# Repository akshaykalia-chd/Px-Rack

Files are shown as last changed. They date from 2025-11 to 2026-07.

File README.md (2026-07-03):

## What is a PX-Rack

Personal Experience Rack, or PX-Rack, is a modular DIY computer rack-style enclosure built for creators who value scalability, customization, and hands-on engineering. Designed to integrate multiple [Mini-ITX](https://en.wikipedia.org/wiki/Mini-ITX) motherboards into a single compact unit, PX-Rack is ideal for homelabs, clustered compute nodes, or multi-OS test environments.

The first use case is [Broadcom VMware Cloud Foundation](https://www.vmware.com/products/cloud-infrastructure/vmware-cloud-foundation). 

## 🛠️ Skills Required to Build a PX-Rack

Building a PX-Rack is not a beginner project. You will need:

1. **Miter saw** — for cutting extrusions and structural components to precise lengths
2. **Soldering** — primarily a safety net for human error during wiring
3. **Specialty tools** — screwdrivers and Allen keys in M2, M3, and M4 sizes, plus Torx drivers T2, T3, and T4
4. **ATX power supply disassembly** — you will need to open and modify a standard ATX PSU

> If any of these sound daunting, that is perfectly reasonable. Reach out using the details in the [Contact details](#-contact-details) section to order a pre-built PX-Rack — or engage directly with the designer if you are mad enough to attempt this yourself.

### 2-Node PX-Rack Enclosure: ### 
#### Render:
2-Node Render

#### Actual: 

Not built, hence no images are available. However, it will be identical to the bottom half of a 4-node enclosure.

### 4-Node PX-Rack Enclosure: ### 
#### Render:
4-Node Render

#### Actual:
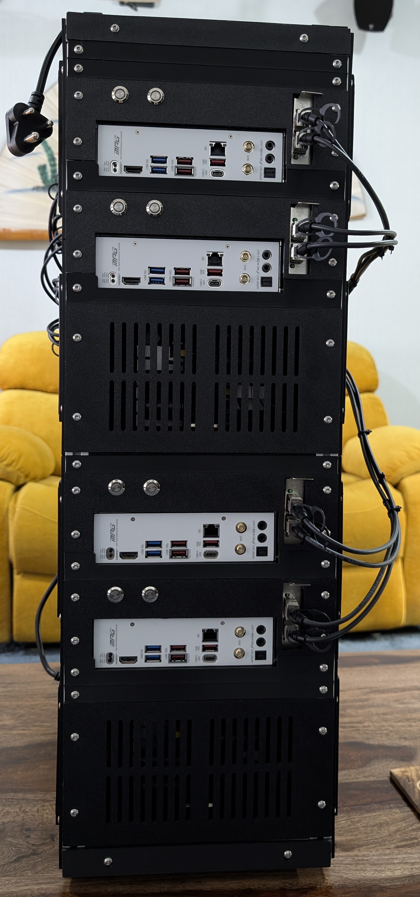
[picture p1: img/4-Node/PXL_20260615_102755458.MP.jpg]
4-Node actual 1

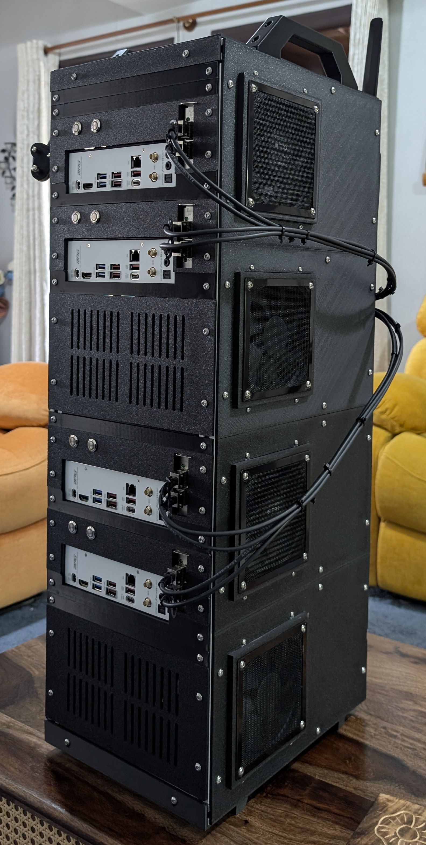
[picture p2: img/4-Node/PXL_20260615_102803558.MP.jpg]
4-Node actual 2

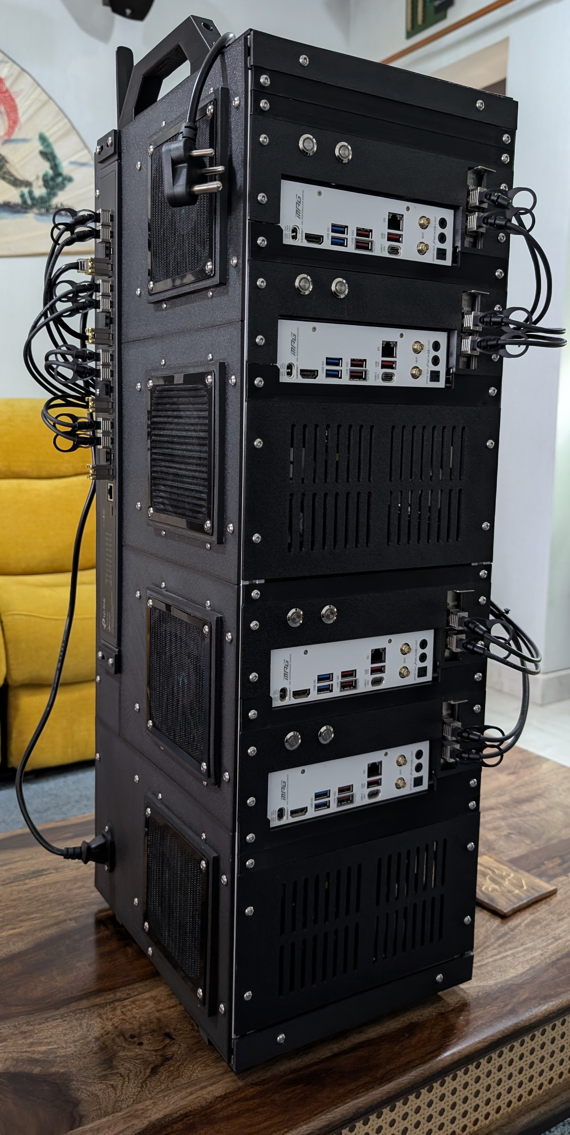
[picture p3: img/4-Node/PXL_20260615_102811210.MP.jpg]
4-Node actual 3

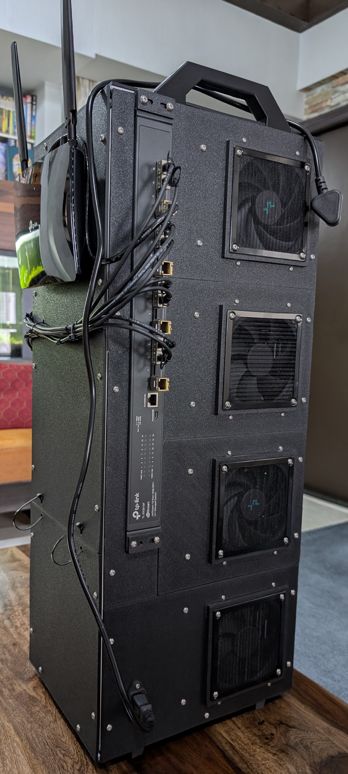
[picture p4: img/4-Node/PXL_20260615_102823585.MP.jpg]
4-Node actual 4

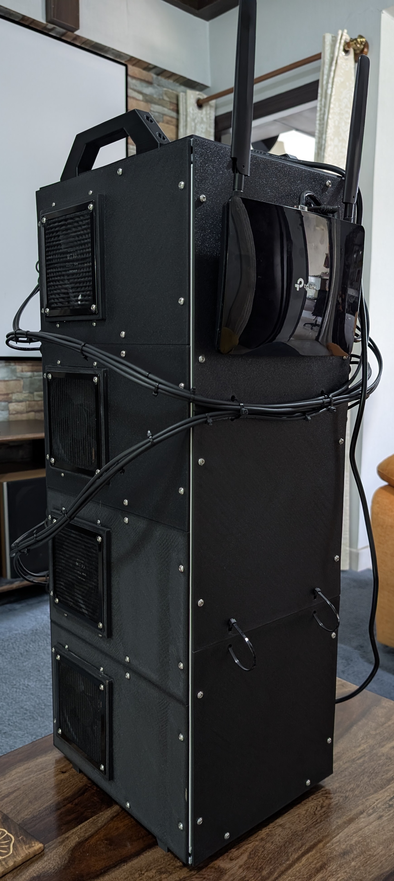
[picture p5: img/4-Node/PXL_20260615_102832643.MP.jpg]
4-Node actual 5


### PX-Rack vs Full Tower
On the left is PX-Rack, and on the right is the Cooler Master Full Tower Case.

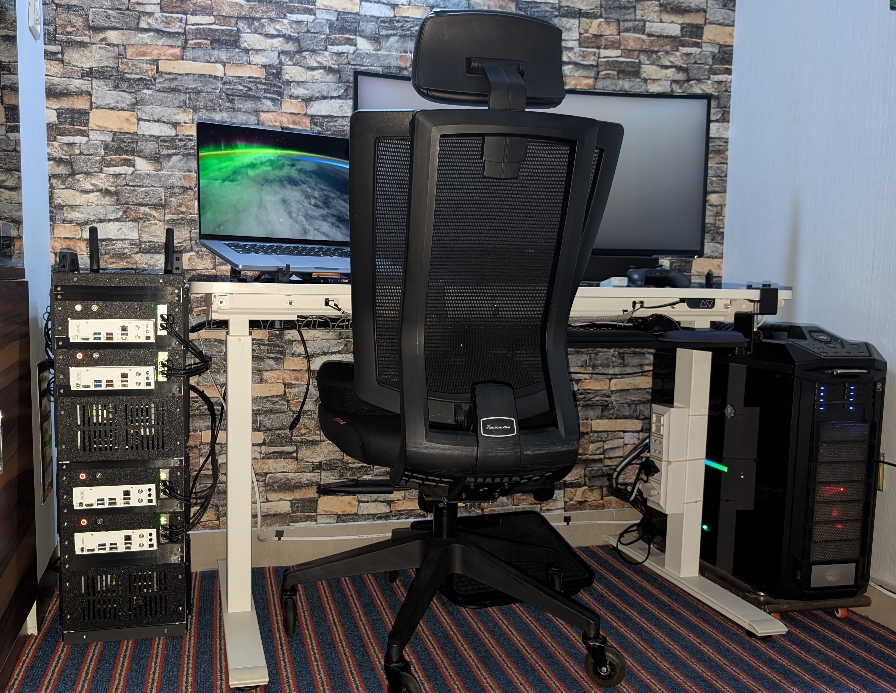
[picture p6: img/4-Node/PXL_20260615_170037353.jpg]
4-Node actual 5


<video width="600" controls>
  <source src="img/4-Node/PXL_20260615_170057228%7E2.mp4" type="video/mp4">
</video>

## What sets PX-Rack apart? 

It is Portable, Purpose-Built, and Open-Source

**🔌 Streamlined Power Management**
Unlike traditional racks designed for data centers or server rooms, PX-Rack is purpose-built for commercial hardware. Instead of juggling multiple external power cables, PX-Rack aggregates multiple power supplies into a single external cable using PCT wire connectors.
- No need for extension cords
- No soldering required
- Clean, efficient cable management

**PCT wire connectors:**

PCT 2-Terminal
PCT 2T
PCT 3x2

**📏 Optimized Dimensions**
Width and length — not height — are the critical factors in PX-Rack’s design. 10 Gb optical fiber cables are neatly routed from the side and back to a switch integrated into the rack. The cables move with the rack, so there is no need to recable when shifting locations. With switch I/O remaining easily accessible, network retopology is straightforward — a true lab must-have.

**🛠 Maker-Friendly Construction**
Most of PX-Rack’s structural components are 3D-printable, making it accessible and affordable for solo builders and makers.
- STL files available via GitHub
- No proprietary parts
- Community-driven, open-source flexibility

**🌬 Airflow & Multi-Node Freedom**
Whether you’re optimizing airflow, managing cables, or experimenting with multi-node setups, PX-Rack gives you the freedom to build infrastructure your way. It’s a platform designed for experimentation, customization, and scalability.

## Why PX-Rack?

_A Mini-ITX cluster enclosure with integrated power management — purpose-built for homelabbers_

### The Problem

Homelabbers and VMware/VCF engineers in India building multi-node compute environments face a painful choice: import an expensive, generic rack cabinet that wasn't designed for their use case, or cobble something together with zip ties and a shelf. Neither works for a professional-grade homelab or demo rig.

### PX-Rack vs DeskPi

| Feature | PX-Rack | DeskPi |
|---|---|---|
| Price (India, enclosure only) | 2-Node ~INR 15,000 / 4-Node ~INR 22,000 | T0-Plus ~INR 9,000–11,000 + customs / T2 Light ~INR 16,000–20,000 + customs |
| Integrated power management | Yes | No |
| Purpose-built for Mini-ITX clusters | Yes | No — generic cabinet |
| Direct crossover network ready (2-Node) | Yes | No |
| Integrated switch bay (4-Node) | Yes | No |
| Mini-ITX motherboards housed | 2 (2-Node) / 4 (4-Node) | User-supplied, bare cabinet |
| PCIe expansion | 1x half-height slot per node | Depends on user's own case/riser |
| 2.5" disk bays | 8 total (2-Node) / 16 total (4-Node) | User-supplied |
| ATX PSUs, pre-wired to single AC inlet | 2 (2-Node) / 4 (4-Node) | User sources & wires own PSU(s) |
| Cooling fans preinstalled (PSU + compute, push-pull) | 4x 120mm (2-Node) / 8x 120mm (4-Node) | User adds own fans |
| Custom 5–12V power delivery for peripherals (on request) | Yes | No |
| 3D-printable / customizable | Yes | No |

### Dimensions

| | Depth | Width | Height |
|---|---|---|---|
| 2-Node | 300mm | 248mm | 375mm |
| 4-Node | 300mm | 248mm | 750mm (also fits a full-width 1U switch/router) |

### PX-Rack vs Standard 1U/2U Rack Servers

- **Compute density**: PX-Rack 4-Node = 4 independent Mini-ITX nodes vs 1 dual-socket board in a typical 1U/2U server
- **Cooling**: PX-Rack runs 8x 120mm fans, push-pull, at fixed full speed at all times (no fan curve) vs small high-RPM fans in 1U / larger slower fans in 2U that usually ramp with load
- **Noise, system off**: baseline room noise vs ~25 dBA idle (1U, e.g. Dell PowerEdge R630) / ~30–40 dBA idle (2U)
- **Noise, system running**: PX-Rack ~78 dB (constant, since fans never throttle down) vs 1U servers commonly high-70s to 90+ dB under full load ("jet engine" fan spin-up is a known 1U trait), 2U servers ~38–65 dB.

Is 78 dB loud for server gear? 

Not particularly — it lands inside the range enterprise 1U servers reach under full thermal load. It's louder than a 2U server, but that's expected: PX-Rack is doing 1U-style airflow work across 4 independent nodes, not one, and its fans run at fixed full speed continuously rather than ramping with load. It is possible to tune the Mini-ITX motherboards to run quiet. However, this many cause CPU to thermal throttle.

_How it was measured:_ 

Google Pixel 8 Pro decibel-meter app, phone placed directly on top of the chassis, comparing system-off vs system-on. This is a near-field, single-device reading, not a calibrated sound meter at the standardized 1-meter bystander position vendor datasheets use — so it's a directional comparison, not a strict apples-to-apples one. If anything, the PX-Rack number likely reads a bit higher than an equivalent 1m measurement would.

### Core Value Arguments

1. **Integrated Power** — DeskPi gives you a bare cabinet with no power story; you run your own cables and figure out PDUs. PX-Rack aggregates all node power into one external connection: one plug in, cleaner cable runs, no external PDU needed.
2. **Purpose over generic** — DeskPi sells an empty cabinet designed for anything. PX-Rack's form factor, cable routing, and power topology are built specifically for Mini-ITX cluster nodes.
3. **India-first, no import friction** — no customs, no 20–30% import duty, no 3–6 week shipping wait, no warranty risk from courier damage. Ships from Bengaluru.
4. **Built for the homelab/VCF use case** — designed for Broadcom VMware Cloud Foundation multi-node lab deployments.
5. **Open, modifiable, repairable** — every structural part is 3D-printable in ABS, PETG, or PLA. Broke a bracket? Print a new one in 2 hours.
6. **Natural upgrade path** — start with 2-Node at ~INR 15,000, expand to 4-Node with switch bay at ~INR 22,000 as your lab grows.

### Who This Is For

- VMware/VCF engineers building a personal lab rig
- Homelabbers who want a clean, portable, rackable cluster — not a desk full of towers
- IT teams needing a compact demo environment they can carry to client sites
- 3D printing enthusiasts who want to contribute to or customize an open-source hardware project

### The Engineering Effort Behind It

Worth saying plainly, without dressing it up: PX-Rack was designed and built by one person, in under 12 months, from a first sketch to a working 4-node unit. No one else on the team contributed to design or build work — teammates gave feedback along the way that genuinely helped shape the final design, but the mechanical design, wiring, power aggregation, 3D printing, and integration were done solo.

That context matters for judging the failures and the time it took. PX-Rack doesn't reuse an existing enclosure playbook — it isn't a resized server chassis or a repurposed generic cabinet like DeskPi's. It combines Mini-ITX motherboards, multiple ATX power supplies aggregated onto a single AC inlet, HDD trays, and push-pull cooling for both compute and power units, all inside a footprint that also leaves room for a rack switch — without falling back on shortcuts from known, off-the-shelf integration methods.

Given that, the time spent getting to a working 4-Node PX-Rack isn't a sign of a rough process — they're what it costs to solve integration problems that had no existing off-the-shelf answer, without compromising on function to get there.

### Further Reading

- [DeskPi RackMate collection](https://deskpi.com/collections/deskpi-rack-mate)

## Repository structure 
```
PX-Rack/
├──Build_Instructions/
│   ├──README.md      
│
├── STL/
│   ├── ABS/
│   │   ├── PART_NAME01.stl
│   │   ├── PART_NAME02.stl
│   │
│   ├── PLA_PETG/
│   │   ├── PART_Name01.stl
│   │   ├── PART_Name01.stl
│   │
│   ├── Templates/
│   │   ├── TEMPLATE_NAME01.dxf
│   │   ├── TEMPLATE_NAME02.dxf
└── README.md
    └── Introduction to PX-Rack, and licensing.
```
# 📜 Terms and Conditions of Use

By accessing or using the PX-Rack repository, you agree to the following terms:

## 🔧 Personal and Lab Use Only
- This repository is intended solely for **individual, non-commercial use**.
- You may use the provided STL files and documentation to build PX-Rack units for:
  - Personal projects
  - Homelabs
  - Educational setups
  - Non-profit experimentation

## 🚫 Commercial Restrictions
- **Commercial use** of any files, designs, or derivatives is **strictly prohibited** without **explicit written permission** from the repository owner.
- This includes, but is not limited to:
  - Selling printed parts or assembled units
  - Using PX-Rack designs in paid services or commercial installations
  - Distributing modified versions for profit

## 📝 Requesting Permission
- To request commercial usage rights, please contact the repository owner via GitHub or the contact method listed in the main `README.md`.

## 📁 Licensing
- All files are provided "as is" without warranty. Users are responsible for safe printing, assembly, and deployment.
- Redistribution of files must retain original attribution and must not misrepresent the origin or intent of the project.

## 📬 Contact details
- **Name:** Akshay Kalia
- **Email:** akshay@vmzoneblog.com
- **Location:** Bengaluru, Karnataka, India
- **Website:** https://vmzoneblog.com

## FAQs ##

### Why is PDF or STL not loading on Git UI? ###

This behavior is observed when you are connecting to the public GitHub server from a corporate network. Try disabling the VPN and then access the repository.

### What is STL? ###
In 3D printing, STL files are the most common file format used to describe 3D models. STL stands for STereoLithography (or sometimes Standard Triangle Language) and encodes the surface geometry of an object using triangular facets that slicing software can interpret. A slicing software is the tool that converts a 3D model (like an STL file) into layer-by-layer instructions (G-code) that a printer can understand and execute. 

### What is ABS? ###
ABS stands for Acrylonitrile Butadiene Styrene. It is a thermoplastic polymer widely used in 3D printing, especially with FDM (Fused Deposition Modeling) printers. Known for being strong, durable, and impact-resistant, ABS is the same material used in LEGO bricks, car dashboards, and protective housings.

The glass transition temperature of ABS is between 100 and 120 °C. Hence, it is best suited for components operating close to heat-generating parts in the PX-Rack.

### What is PETG? ### 

PETG stands for Polyethylene Terephthalate Glycol-modified. It is a thermoplastic derived from PET (the same plastic used in water bottles), with glycol added to improve durability and reduce brittleness. PETG combines the ease of printing of PLA with the strength and heat resistance of ABS, making it a versatile middle-ground filament.

The glass transition temperature of PETG is between 80 and 100 °C. While it can be used for external parts, it is not suitable for components operating in the vicinity of heat-generating elements in the PX-Rack.

### What is PLA? ###
PLA stands for Polylactic Acid. It is a biodegradable thermoplastic made from renewable resources such as corn starch or sugarcane. PLA is the most widely used filament in desktop 3D printing because it is easy to print, affordable, and environmentally friendly compared to petroleum-based plastics like ABS.

However, the glass transition temperature of PLA lies between 60 and 80 °C. As a result, a large number of PX-Rack components cannot be manufactured using PLA.

PLA should only be used for printing PX-Rack parts as a last resort when printing in PETG is not possible.

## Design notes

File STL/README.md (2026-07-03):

This folder contains all STL files needed to 3D print the various parts of the PX-Rack.

The `Templates/` subfolder contains DXF files used as importable modules within the part designs. Where multiple parts require the exact same cut (side panels, top/bottom covers, and the switch bush), the cut was defined once as a DXF template and imported into each design for consistency, rather than being redrawn each time.

## FAQs ##

### What is STL? ###

In 3D printing, STL files are the most common file format used to describe 3D models. STL stands for STereoLithography (or sometimes Standard Triangle Language) and encodes the surface geometry of an object using triangular facets that slicing software can interpret. A slicing software is the tool that converts a 3D model (like an STL file) into layer-by-layer instructions (G-code) that a printer can understand and execute. 

### What is ABS? ###

ABS stands for Acrylonitrile Butadiene Styrene. It is a thermoplastic polymer widely used in 3D printing, especially with FDM (Fused Deposition Modeling) printers. Known for being strong, durable, and impact-resistant, ABS is the same material used in LEGO bricks, car dashboards, and protective housings.

The glass transition temperature of ABS is between 100 and 120 °C. Hence, it is best suited for components operating close to heat-generating parts in the PX-Rack.

### What is PETG? ### 

PETG stands for Polyethylene Terephthalate Glycol-modified. It is a thermoplastic derived from PET (the same plastic used in water bottles), with glycol added to improve durability and reduce brittleness. PETG combines the ease of printing of PLA with the strength and heat resistance of ABS, making it a versatile middle-ground filament.

The glass transition temperature of PETG is between 80 and 100 °C. While it can be used for external parts, it is not suitable for components operating in the vicinity of heat-generating elements in the PX-Rack.

### What is PLA? ###

PLA stands for Polylactic Acid. It is a biodegradable thermoplastic made from renewable resources such as corn starch or sugarcane. PLA is the most widely used filament in desktop 3D printing because it is easy to print, affordable, and environmentally friendly compared to petroleum-based plastics like ABS.

However, the glass transition temperature of PLA lies between 60 and 80 °C. As a result, a large number of PX-Rack components cannot be manufactured using PLA.

PLA should only be used for printing PX-Rack parts as a last resort when printing in PETG is not possible.

### What quality parameters should be used for 3D prints? ###

You can find these details in the README files located under /STL/ABS and /STL/PLA_PETG.

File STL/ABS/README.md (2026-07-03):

## Folder Contents: ## 

This folder contains 10 STL files as under: 

1. Foot.stl
2. HDD-Mount.stl
3. HDD-Mount-Back-Plate.stl
4. MB-IO-Panel.stl
5. MB-Mount-Back-Plate.stl
6. MB-Mounting-Plate.stl
7. Power-Mount-Back-Plate.stl
8. Power-Mount-Base.stl
9. Power-Mount-Grill.stl
10. Power-Mount-PCB-Holder-Plate.stl

The STL must be printed using the following parameters at a minimum. Stronger and higher-quality configurations are acceptable.

## 3D Print parameters ##

### Quality ###

1. Material: ABS/ABS+
2. Infill: 20% or above
3. Layer height: 0.2 mm
4. First Layer height: 0.24 mm
5. Precise Wall: True
6. Wall loops: 4

### Strength ###

1. Top Surface pattern: Monotonic Line 
2. Bottom Surface pattern: Monotonic Line
3. Sparse Infill density: 20%
4. Sparse Infill pattern: Gyroid
5. Internal solid Infill pattern: Monotonic

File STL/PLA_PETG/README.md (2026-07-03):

## Folder Contents: ## 

This folder contains 13 STL files as under: 

1. 240mm-Banding.stl
2. 25x265 Banding.stl
3. 3mm-SwithBush.stl
4. 5mm-Swith-bush.stl
5. Back-Cover.stl
6. Bottom-cover.stl
7. Fan-Cut-120.stl
8. Handel.stl
9. Left-Side-Panel-120mm-Fan-Power-Cut.stl
10. Left-Side-Panel-120mm-Fan-Switch-Cut.stl
11. Right-Side-Panel-120mm-Fan-Cut.stl
12. Switch-Banding.stl
13. Top-Cover.stl

The STL must be printed using the following parameters at a minimum. Stronger and higher-quality configurations are acceptable.

## 3D Print parameters ##

### Quality ###

1. Material: Ranked recommendation
   1. PETG-Pro
   2. PETG
   3. PLA-Pro
   4. PLA
2. Infill: 20% or above
3. Layer height: 0.2 mm
4. First Layer height: 0.24 mm
5. Precise Wall: True

### Strength ###

1. Top Surface pattern: Monotonic Line 
2. Bottom Surface pattern: Monotonic Line
3. Sparse Infill density: 20%
4. Sparse Infill pattern: Gyroid
5. Internal solid Infill pattern: Monotonic

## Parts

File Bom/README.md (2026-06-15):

The File covers the quantity of various parts required to build a PX-Rack enclosure

### 2-Node Px-Rack Enclosure: ### 

2-Node Render

A 2 node PX-Rack enclosure has 17 parts that need 3D printing. The quantity of each part required is as under

1. [Foot.stl](../STL/ABS/Foot.stl) - 4
2. [HDD-Mount.stl](../STL/ABS/HDD-Mount.stl) - 2
3. [HDD-Mount-Back-Plate.stl](../STL/ABS/HDD-Mount-Back-Plate.stl) -2
4. [MB-IO-Panel.stl](../STL/ABS/MB-IO-Panel.stl) -2
5. [MB-Mount-Back-Plate.stl](../STL/ABS/MB-Mount-Back-Plate.stl) - 2
6. [MB-Mounting-Plate.stl](../STL/ABS/MB-Mounting-Plate.stl) - 2
7. [Power-Mount-Back-Plate.stl](../STL/ABS/Power-Mount-Back-Plate.stl) - 1
8. [Power-Mount-Base.stl](../STL/ABS/Power-Mount-Base.stl) - 1
9. [Power-Mount-Grill.stl](../STL/ABS/Power-Mount-Grill.stl) - 1
10. [Power-Mount-PCB-Holder-Plate.stl](../STL/ABS/Power-Mount-PCB-Holder-Plate.stl) -1
11. [25x265 Banding.stl](../STL/PLA_PETG/25x265%20Banding.stl) - 2
12. [Back-Cover.stl](../STL/PLA_PETG/Back-Cover.stl) - 2
13. [Bottom-cover.stl](../STL/PLA_PETG/Bottom-cover.stl) - 1
14. [Handel.stl](../STL/PLA_PETG/Handel.stl) - 2
15. [Left-Side-Panel-120mm-Fan-Power-Cut.stl](../STL/PLA_PETG/Left-Side-Panel-120mm-Fan-Power-Cut.stl) - 1
16. [Right-Side-Panel-120mm-Fan-Cut.stl](../STL/PLA_PETG/Right-Side-Panel-120mm-Fan-Cut.stl) - 3
17. [Top-Cover.stl](../STL/PLA_PETG/Top-Cover.stl) - 1

### 4-Node Px-Rack Enclosure: ### 

4-Node Render

A 4 node PX-Rack enclosure has 22 parts that need 3D printing. The quantity of each part required is as under

1. [Foot.stl](../STL/ABS/Foot.stl) - 4
2. [HDD-Mount.stl](../STL/ABS/HDD-Mount.stl) - 4
3. [HDD-Mount-Back-Plate.stl](../STL/ABS/HDD-Mount-Back-Plate.stl) - 4
4. [MB-IO-Panel.stl](../STL/ABS/MB-IO-Panel.stl) - 4
5. [MB-Mount-Back-Plate.stl](../STL/ABS/MB-Mount-Back-Plate.stl) - 4
6. [MB-Mounting-Plate.stl](../STL/ABS/MB-Mounting-Plate.stl) - 4
7. [Power-Mount-Back-Plate.stl](../STL/ABS/Power-Mount-Back-Plate.stl) - 2
8. [Power-Mount-Base.stl](../STL/ABS/Power-Mount-Base.stl) - 2
9. [Power-Mount-Grill.stl](../STL/ABS/Power-Mount-Grill.stl) - 2
10. [Power-Mount-PCB-Holder-Plate.stl](../STL/ABS/Power-Mount-PCB-Holder-Plate.stl) - 2
11. [3mm-SwithBush.stl](../STL/PLA_PETG/3mm-SwithBush.stl) - 2
12. [5mm-Swith-bush.stl](../STL/PLA_PETG/5mm-Swith-bush.stl) - 2
13. [25x265 Banding.stl](../STL/PLA_PETG/25x265%20Banding.stl) - 2
14. [240mm-Banding.stl](../STL/PLA_PETG/240mm-Banding.stl) - 1
15. [Back-Cover.stl](../STL/PLA_PETG/Back-Cover.stl) - 4
16. [Bottom-cover.stl](../STL/PLA_PETG/Bottom-cover.stl) - 1
17. [Handel.stl](../STL/PLA_PETG/Handel.stl) - 2
18. [Left-Side-Panel-120mm-Fan-Power-Cut.stl](../STL/PLA_PETG/Left-Side-Panel-120mm-Fan-Power-Cut.stl) - 1
19. [Left-Side-Panel-120mm-Fan-Switch-Cut.stl](../STL/PLA_PETG/Left-Side-Panel-120mm-Fan-Switch-Cut.stl) - 3
20. [Right-Side-Panel-120mm-Fan-Cut.stl](../STL/PLA_PETG/Right-Side-Panel-120mm-Fan-Cut.stl) - 4
21. [Switch-Banding.stl](../STL/PLA_PETG/Switch-Banding.stl) - 1
22. [Top-Cover.stl](../STL/PLA_PETG/Top-Cover.stl) - 1

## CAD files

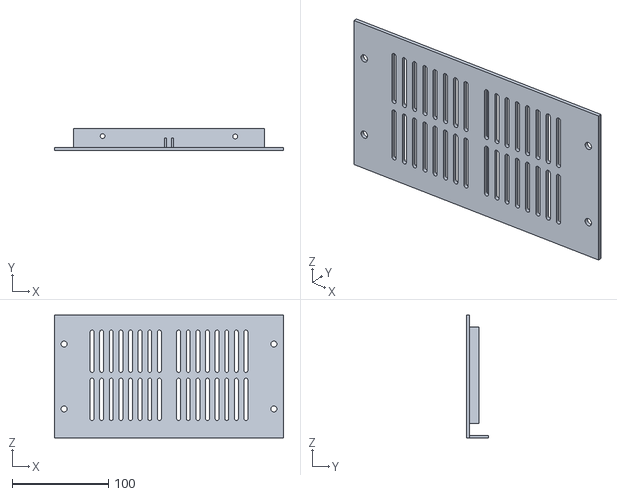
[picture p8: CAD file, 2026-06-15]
STL/ABS/Power-Mount-Grill.stl
238.0 x 23.0 x 127.5

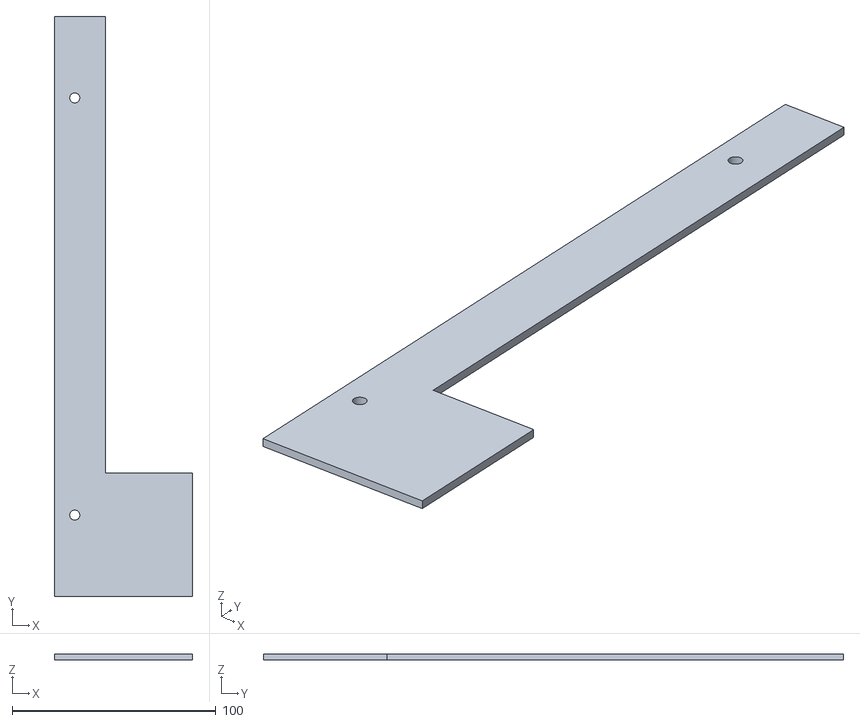
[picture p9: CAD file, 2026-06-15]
STL/PLA_PETG/Switch-Banding.stl
67.9 x 285.0 x 3.00

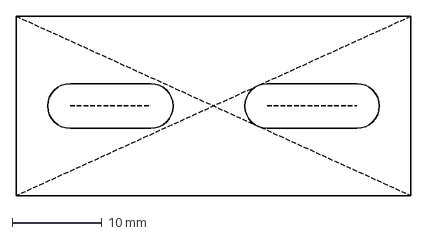
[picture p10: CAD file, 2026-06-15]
STL/Templates/SwithBush.dxf
44.0 x 20.0 mm

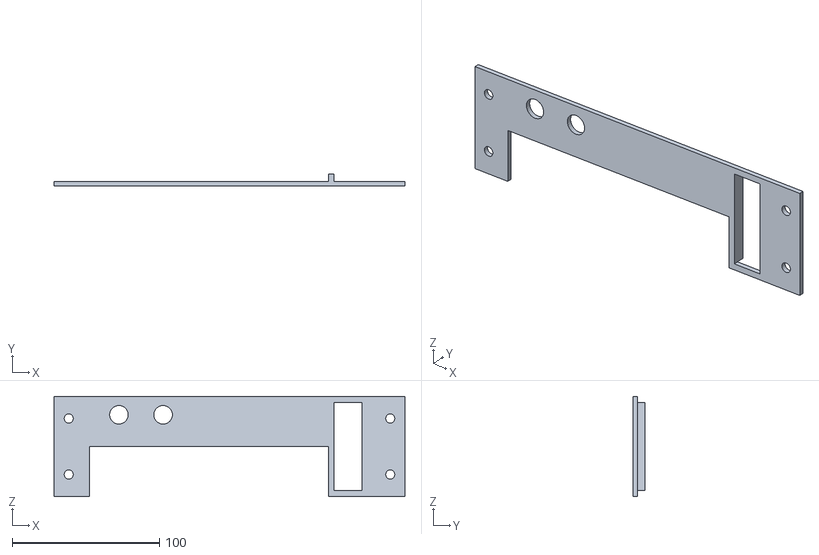
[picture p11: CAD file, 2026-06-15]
STL/ABS/MB-IO-Panel.stl
238.0 x 8.00 x 68.0

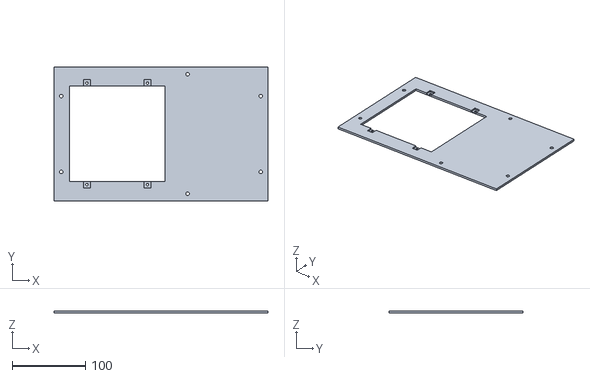
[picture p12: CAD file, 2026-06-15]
STL/PLA_PETG/Right-Side-Panel-120mm-Fan-Cut.stl
293.0 x 183.8 x 3.00

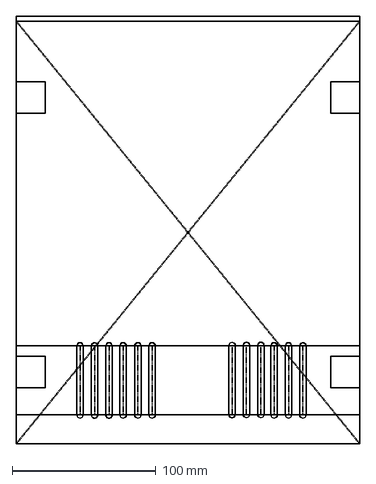
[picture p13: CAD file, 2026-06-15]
STL/Templates/Top-Bot-Covers.dxf
239.0 x 297.5 mm

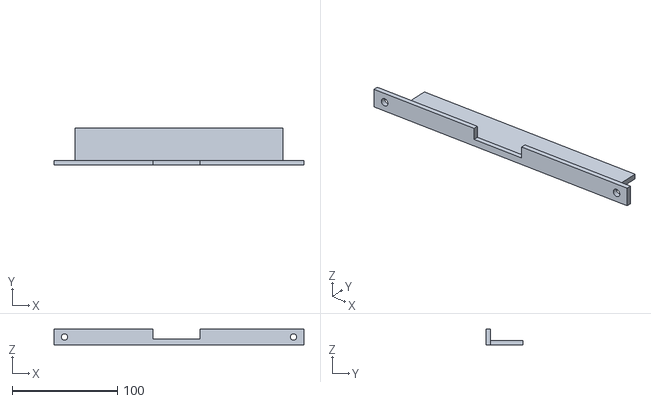
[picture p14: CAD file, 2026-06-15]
STL/ABS/HDD-Mount-Back-Plate.stl
238.0 x 35.0 x 15.0

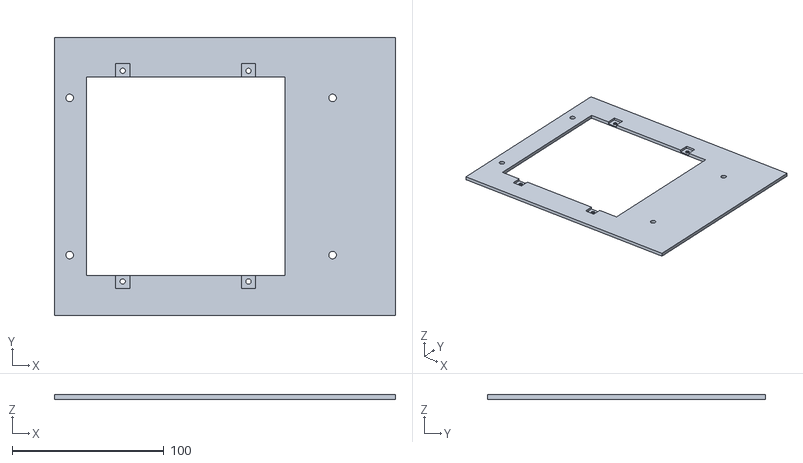
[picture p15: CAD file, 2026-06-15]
STL/PLA_PETG/Left-Side-Panel-120mm-Fan-Switch-Cut.stl
225.0 x 183.8 x 3.00

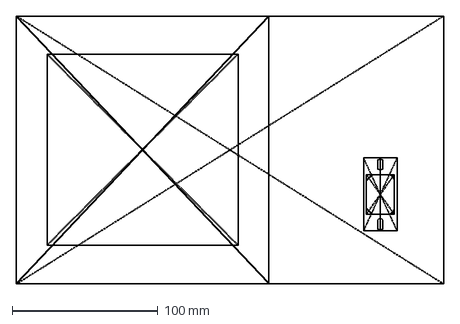
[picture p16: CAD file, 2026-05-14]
STL/Templates/Cover-Template.dxf
293.0 x 183.8 mm

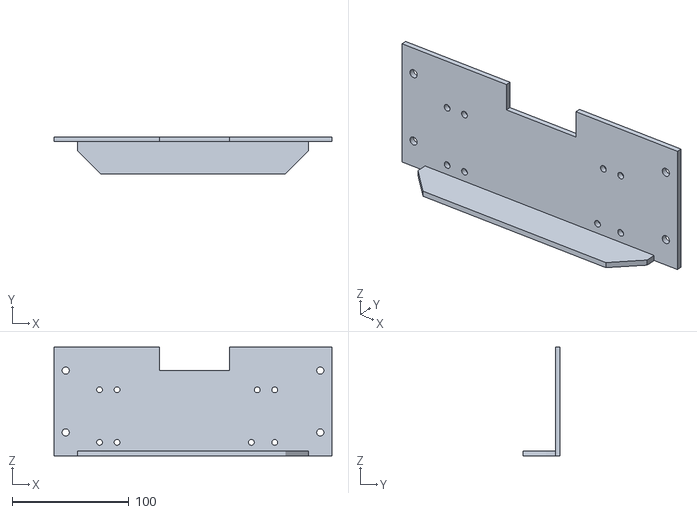
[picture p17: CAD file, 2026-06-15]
STL/ABS/MB-Mount-Back-Plate.stl
238.0 x 31.9 x 93.0

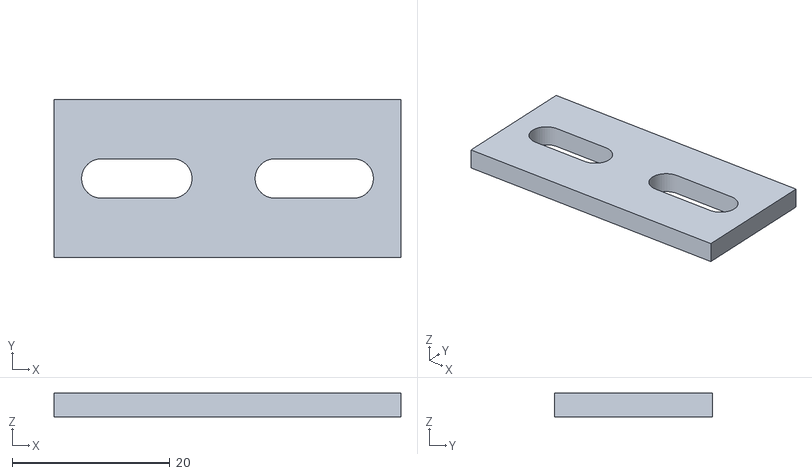
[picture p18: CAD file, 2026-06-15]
STL/PLA_PETG/3mm-SwithBush.stl
44.0 x 20.0 x 3.00

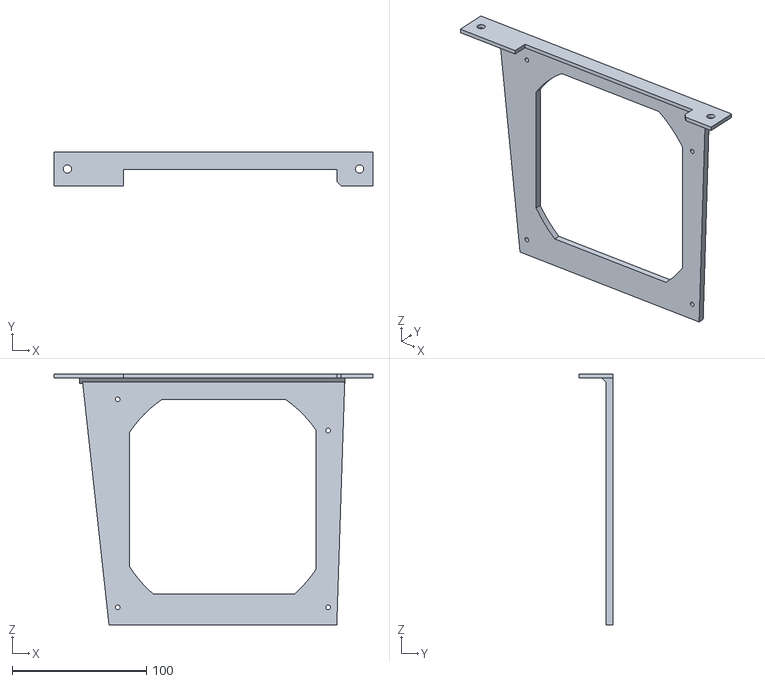
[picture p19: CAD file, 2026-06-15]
STL/ABS/MB-Mounting-Plate.stl
238.0 x 25.0 x 187.0

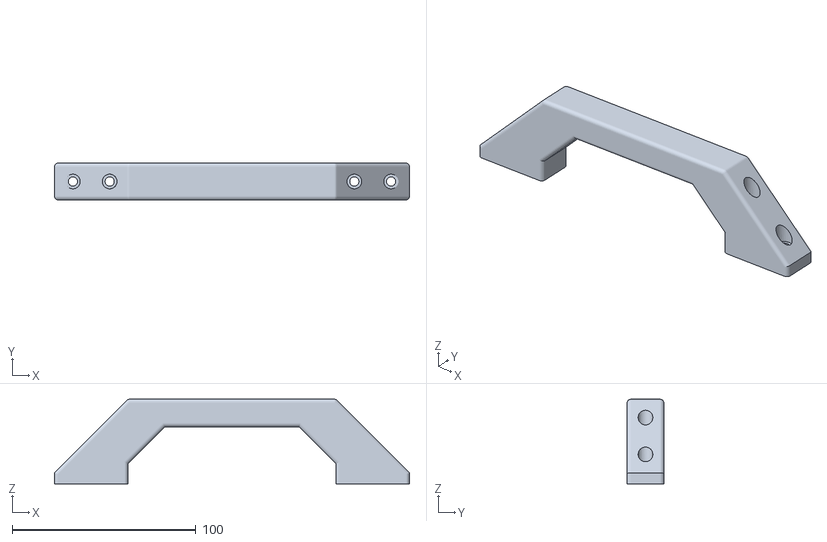
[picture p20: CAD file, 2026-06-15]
STL/PLA_PETG/Handel.stl
193.0 x 20.0 x 46.0

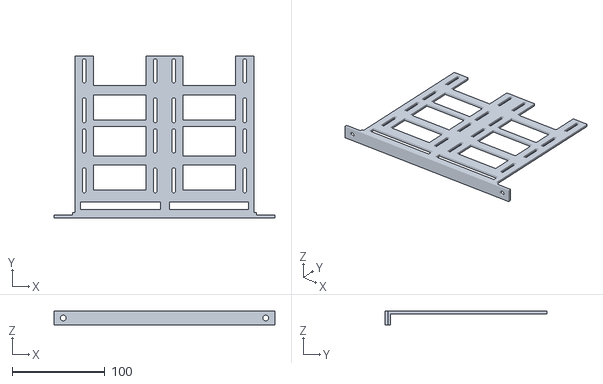
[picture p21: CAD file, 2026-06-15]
STL/ABS/HDD-Mount.stl
238.0 x 174.5 x 15.0

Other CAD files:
STL/PLA_PETG/25x265 Banding.stl
STL/ABS/Power-Mount-Back-Plate.stl
STL/PLA_PETG/5mm-Swith-bush.stl
STL/ABS/Foot.stl
STL/ABS/Power-Mount-Base.stl
STL/ABS/Power-Mount-PCB-Holder-Plate.stl
STL/PLA_PETG/240mm-Banding.stl
STL/PLA_PETG/Back-Cover.stl
STL/PLA_PETG/Bottom-cover.stl
STL/PLA_PETG/Fan-Cut-120.stl
STL/PLA_PETG/Left-Side-Panel-120mm-Fan-Power-Cut.stl
STL/PLA_PETG/Top-Cover.stl

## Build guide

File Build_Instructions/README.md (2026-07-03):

The file covers the quantity of various parts required to build a PX-Rack enclosure.

For step-by-step build instructions, see [Assembly-Steps.md](Assembly-Steps.md).

### 2-Node PX-Rack Enclosure: ### 

2-Node Render

A 2-node PX-Rack enclosure has 18 parts that need 3D printing. The quantity of each part required is as under:

1. [Foot.stl](../STL/ABS/Foot.stl) - 4
2. [HDD-Mount.stl](../STL/ABS/HDD-Mount.stl) - 2
3. [HDD-Mount-Back-Plate.stl](../STL/ABS/HDD-Mount-Back-Plate.stl) - 2
4. [MB-IO-Panel.stl](../STL/ABS/MB-IO-Panel.stl) - 2
5. [MB-Mount-Back-Plate.stl](../STL/ABS/MB-Mount-Back-Plate.stl) - 2
6. [MB-Mounting-Plate.stl](../STL/ABS/MB-Mounting-Plate.stl) - 2
7. [Power-Mount-Back-Plate.stl](../STL/ABS/Power-Mount-Back-Plate.stl) - 1
8. [Power-Mount-Base.stl](../STL/ABS/Power-Mount-Base.stl) - 1
9. [Power-Mount-Grill.stl](../STL/ABS/Power-Mount-Grill.stl) - 1
10. [Power-Mount-PCB-Holder-Plate.stl](../STL/ABS/Power-Mount-PCB-Holder-Plate.stl) - 1
11. [25x265 Banding.stl](../STL/PLA_PETG/25x265%20Banding.stl) - 2
12. [Back-Cover.stl](../STL/PLA_PETG/Back-Cover.stl) - 2
13. [Bottom-cover.stl](../STL/PLA_PETG/Bottom-cover.stl) - 1
14. [Handel.stl](../STL/PLA_PETG/Handel.stl) - 2
15. [Left-Side-Panel-120mm-Fan-Power-Cut.stl](../STL/PLA_PETG/Left-Side-Panel-120mm-Fan-Power-Cut.stl) - 1
16. [Right-Side-Panel-120mm-Fan-Cut.stl](../STL/PLA_PETG/Right-Side-Panel-120mm-Fan-Cut.stl) - 3
17. [Top-Cover.stl](../STL/PLA_PETG/Top-Cover.stl) - 1
18. [Fan-Cut-120.stl](../STL/PLA_PETG/Fan-Cut-120.stl) - 4

To assemble a 2-Node PX-Rack enclosure, you will need the following parts:

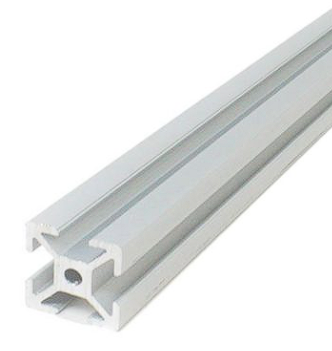
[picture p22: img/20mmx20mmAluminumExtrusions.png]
Aluminum Extrusion
1.  20mm x 20mm Aluminum extrusions of the sizes listed as under 
   1. 350 mm - 6
   2. 200 mm - 4
   3. 300 mm - 4
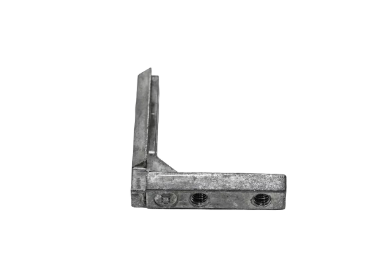
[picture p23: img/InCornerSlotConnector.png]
In Corner Slot Connector
2.  In Corner Slot Connector - 8
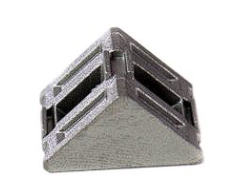
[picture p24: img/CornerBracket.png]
Corner Bracket
3.  Corner Bracket - 16
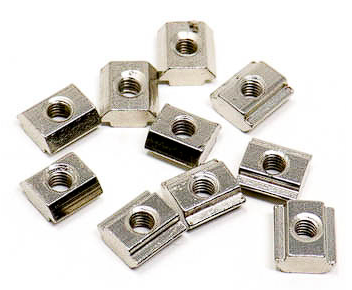
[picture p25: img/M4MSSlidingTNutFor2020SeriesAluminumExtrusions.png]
M4 T-Nut
4.  M4 MS Sliding T Nut For 2020 Series Aluminum extrusions - 150 
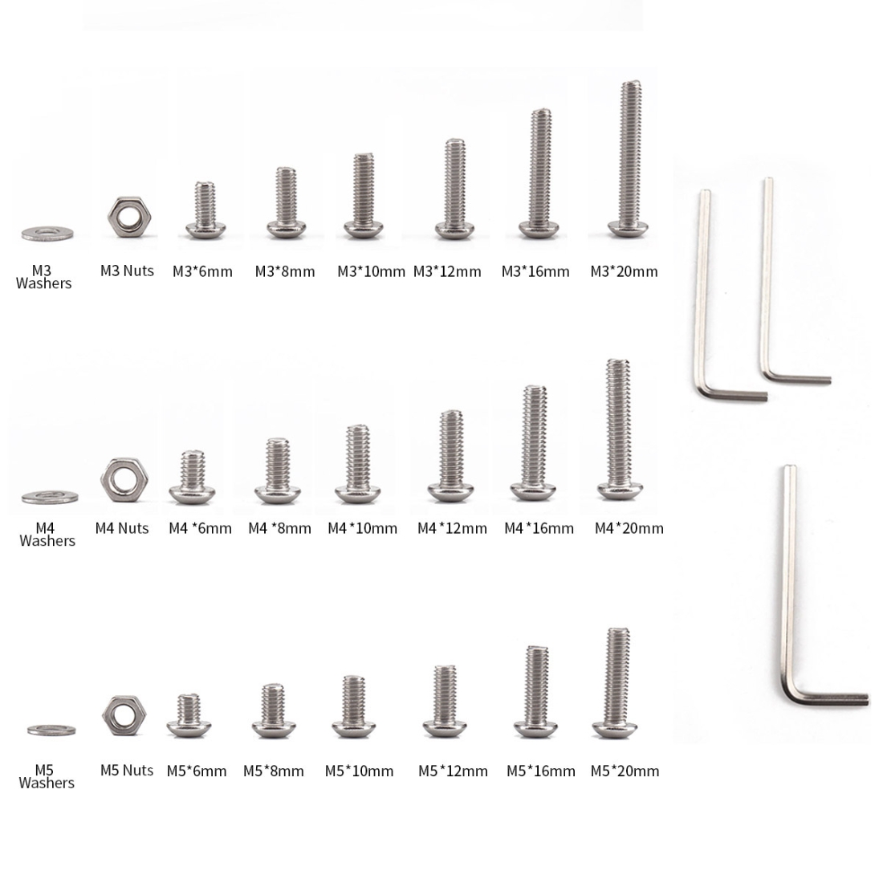
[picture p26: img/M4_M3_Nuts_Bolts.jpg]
M4/M3 Bolt
5.  M4, M3 Nuts and Bolts 10 mm - 20
6. <a href="../img/M4_M3_Nuts_Bolts.jpg">M4/M3 Bolt</a> M4, M3 Nuts and Bolts 12 mm - 20
7. <a href="../img/M4_M3_Nuts_Bolts.jpg">M4/M3 Bolt</a> M4, M3 Nuts and Bolts 16 mm - 20
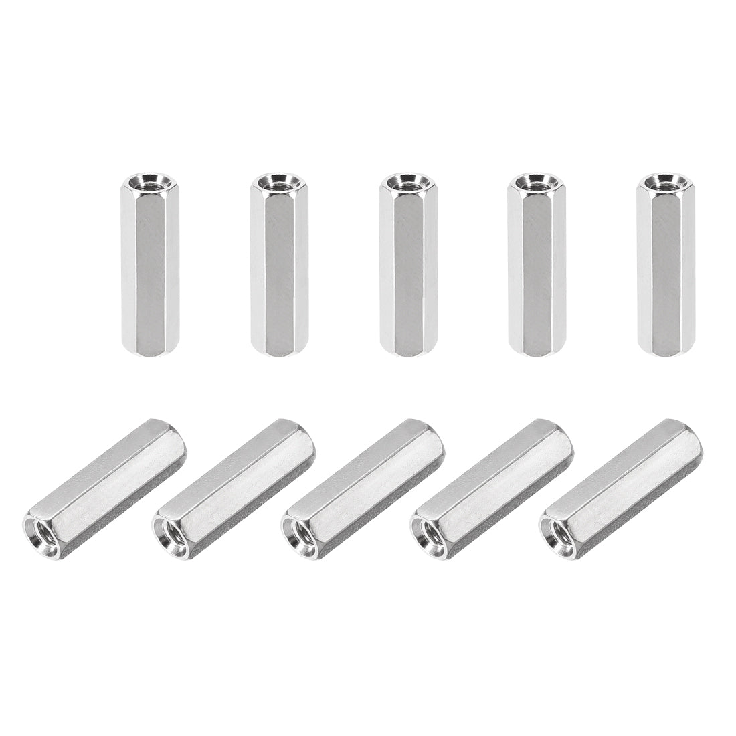
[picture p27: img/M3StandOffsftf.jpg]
M3 Standoff
8.  M3 Standoffs/Spacers Female to Female 10 mm - 30 
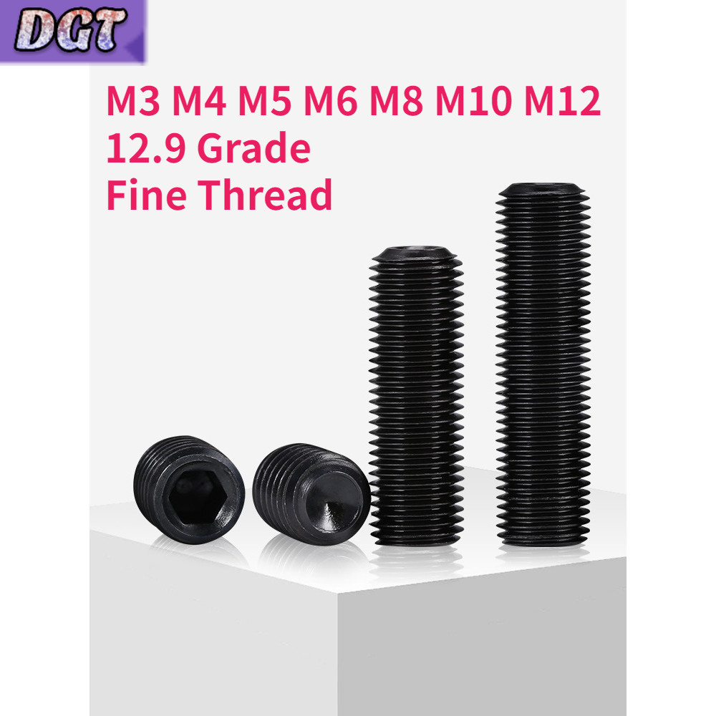
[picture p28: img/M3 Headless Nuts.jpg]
M3 Headless Nut
9.  M3 Headless Nuts 12 mm - 30
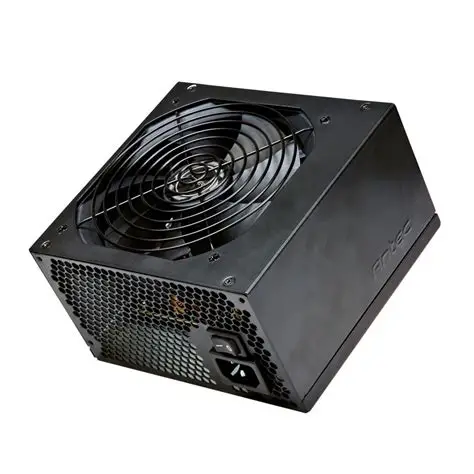
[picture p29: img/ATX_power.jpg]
ATX Power Supply
10.  ATX power supplies 400w - 2
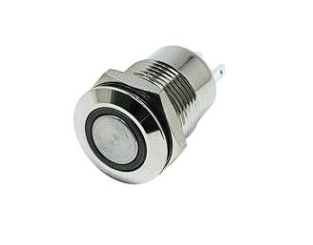
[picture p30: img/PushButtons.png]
Push Button
11.  Push buttons - 4
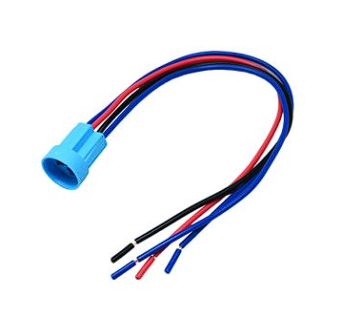
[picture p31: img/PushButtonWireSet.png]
Push Button Wire Set
12.  Push button Wire Set - 4 
13. <a href="../img/LT-633.png">LT-633 Terminal</a> LT-633(SPL-63) Stationary, Type Quick Connection, Terminal - 1
14. <a href="../img/LT-933.png">LT-933 Terminal</a> LT-933(SPL-93) Stationary Type Quick Connection Terminal - 1 
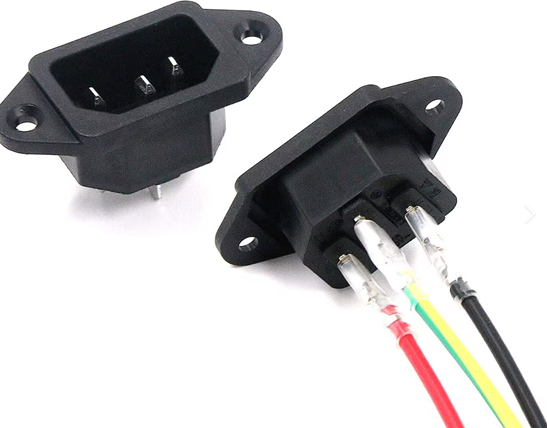
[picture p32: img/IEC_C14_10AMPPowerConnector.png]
IEC C14 Connector
15.  IEC, C14 10 AMP Power connector - 1
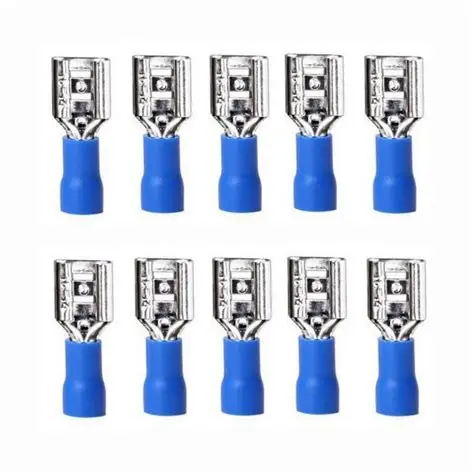
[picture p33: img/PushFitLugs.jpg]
Push Fit Lug
16.  Push Fit lugs compatible with your IEC, C14 10 AMP Power connector - 5 
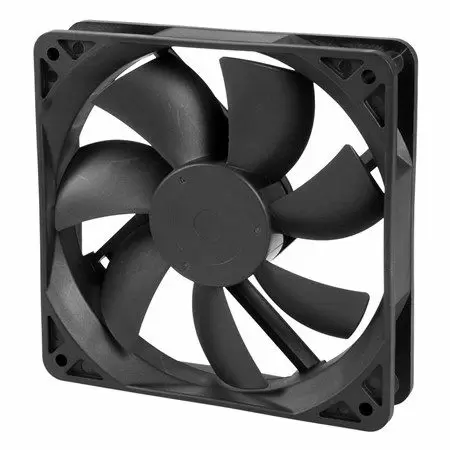
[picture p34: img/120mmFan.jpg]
120mm Fan
17.  120mm Cooling Fans - 2 (additional to the 2 fans included with the 2 ATX PSUs)
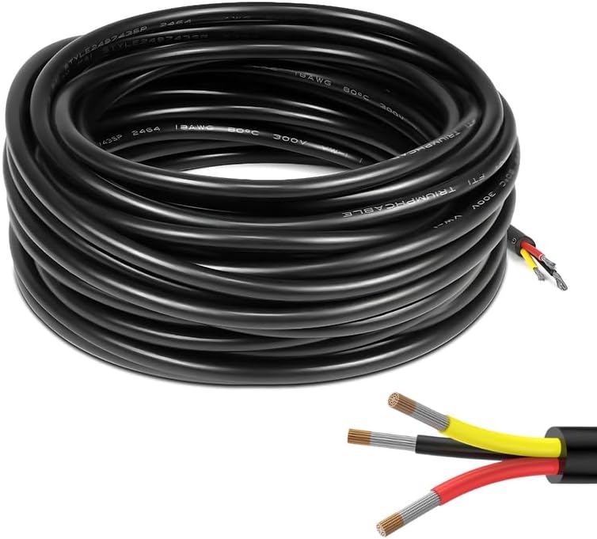
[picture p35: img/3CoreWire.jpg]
3-Core Cable
18.  3-Core 1.5 mm² PVC Insulated Flexible Copper Cable (IS 694) - 5 metre

### 4-Node PX-Rack Enclosure: ### 

4-Node Render

A 4-node PX-Rack enclosure has 23 parts that need 3D printing. The quantity of each part required is as under:

1. [Foot.stl](../STL/ABS/Foot.stl) - 4
2. [HDD-Mount.stl](../STL/ABS/HDD-Mount.stl) - 4
3. [HDD-Mount-Back-Plate.stl](../STL/ABS/HDD-Mount-Back-Plate.stl) - 4
4. [MB-IO-Panel.stl](../STL/ABS/MB-IO-Panel.stl) - 4
5. [MB-Mount-Back-Plate.stl](../STL/ABS/MB-Mount-Back-Plate.stl) - 4
6. [MB-Mounting-Plate.stl](../STL/ABS/MB-Mounting-Plate.stl) - 4
7. [Power-Mount-Back-Plate.stl](../STL/ABS/Power-Mount-Back-Plate.stl) - 2
8. [Power-Mount-Base.stl](../STL/ABS/Power-Mount-Base.stl) - 2
9. [Power-Mount-Grill.stl](../STL/ABS/Power-Mount-Grill.stl) - 2
10. [Power-Mount-PCB-Holder-Plate.stl](../STL/ABS/Power-Mount-PCB-Holder-Plate.stl) - 2
11. [3mm-SwithBush.stl](../STL/PLA_PETG/3mm-SwithBush.stl) - 2
12. [5mm-Swith-bush.stl](../STL/PLA_PETG/5mm-Swith-bush.stl) - 2
13. [25x265 Banding.stl](../STL/PLA_PETG/25x265%20Banding.stl) - 2
14. [240mm-Banding.stl](../STL/PLA_PETG/240mm-Banding.stl) - 1
15. [Back-Cover.stl](../STL/PLA_PETG/Back-Cover.stl) - 4
16. [Bottom-cover.stl](../STL/PLA_PETG/Bottom-cover.stl) - 1
17. [Handel.stl](../STL/PLA_PETG/Handel.stl) - 2
18. [Left-Side-Panel-120mm-Fan-Power-Cut.stl](../STL/PLA_PETG/Left-Side-Panel-120mm-Fan-Power-Cut.stl) - 1
19. [Left-Side-Panel-120mm-Fan-Switch-Cut.stl](../STL/PLA_PETG/Left-Side-Panel-120mm-Fan-Switch-Cut.stl) - 3
20. [Right-Side-Panel-120mm-Fan-Cut.stl](../STL/PLA_PETG/Right-Side-Panel-120mm-Fan-Cut.stl) - 4
21. [Switch-Banding.stl](../STL/PLA_PETG/Switch-Banding.stl) - 1
22. [Top-Cover.stl](../STL/PLA_PETG/Top-Cover.stl) - 1
23. [Fan-Cut-120.stl](../STL/PLA_PETG/Fan-Cut-120.stl) - 8

To assemble a 4-Node PX-Rack enclosure, you will need the following parts:

1. <a href="../img/20mmx20mmAluminumExtrusions.png">Aluminum Extrusion</a> 20mm x 20mm Aluminum extrusions of the sizes listed as under 
   1. 700 mm - 6
   2. 200 mm - 4
   3. 300 mm - 4
   4. 45 mm - 1
2. <a href="../img/InCornerSlotConnector.png">In Corner Slot Connector</a> In Corner Slot Connector - 10
3. <a href="../img/CornerBracket.png">Corner Bracket</a> Corner Bracket - 16
4. <a href="../img/M4MSSlidingTNutFor2020SeriesAluminumExtrusions.png">M4 T-Nut</a> M4 MS Sliding T Nut For 2020 Series Aluminum extrusions - 300 
5. <a href="../img/M4_M3_Nuts_Bolts.jpg">M4/M3 Bolt</a> M4, M3 Nuts and Bolts 10 mm - 40
6. <a href="../img/M4_M3_Nuts_Bolts.jpg">M4/M3 Bolt</a> M4, M3 Nuts and Bolts 12 mm - 40
7. <a href="../img/M4_M3_Nuts_Bolts.jpg">M4/M3 Bolt</a> M4, M3 Nuts and Bolts 16 mm - 40
8. <a href="../img/M3StandOffsftf.jpg">M3 Standoff</a> M3 Standoffs/Spacers Female to Female 10 mm - 60 
9. <a href="../img/M3%20Headless%20Nuts.jpg">M3 Headless Nut</a> M3 Headless Nuts 12 mm - 60
10. <a href="../img/ATX_power.jpg">ATX Power Supply</a> ATX power supplies 400w - 4
11. <a href="../img/PushButtons.png">Push Button</a> Push buttons - 8
12. <a href="../img/PushButtonWireSet.png">Push Button Wire Set</a> Push button Wire Set - 8
13. <a href="../img/LT-633.png">LT-633 Terminal</a> LT-633(SPL-63) Stationary, Type Quick Connection, Terminal - 2
14. <a href="../img/LT-933.png">LT-933 Terminal</a> LT-933(SPL-93) Stationary Type Quick Connection Terminal - 1 
15. <a href="../img/IEC_C14_10AMPPowerConnector.png">IEC C14 Connector</a> IEC, C14 10 AMP Power connector - 1
16. <a href="../img/PushFitLugs.jpg">Push Fit Lug</a> Push Fit lugs compatible with your IEC, C14 10 AMP Power connector - 5 
17. <a href="../img/120mmFan.jpg">120mm Fan</a> 120mm Cooling Fans - 4 (additional to the 4 fans included with the 4 ATX PSUs)
18. <a href="../img/3CoreWire.jpg">3-Core Cable</a> 3-Core 1.5 mm² PVC Insulated Flexible Copper Cable (IS 694) - 5 metre

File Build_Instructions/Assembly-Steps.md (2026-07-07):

## 2-Node PX-Rack — Assembly Steps

This guide sequences the build from the [parts list](README.md). Part quantities below assume a **2-Node** enclosure. Cross-check against the [renders](../img/2-Node.png) and the [4-Node build photos](../img/4-Node) (the 2-Node is the bottom half of a 4-Node) before final tightening, since this sequence is derived from the BOM and photos rather than a dimensioned drawing.

> ⚠️ Mains voltage work (IEC inlet, ATX PSU wiring) is involved. If you are not comfortable opening an ATX PSU or wiring an AC inlet, stop and have it done by someone qualified. Always work with PSUs unplugged and discharged.

### 0. Before you start
1. Print all parts per [STL/ABS/README.md](../STL/ABS/README.md) and [STL/PLA_PETG/README.md](../STL/PLA_PETG/README.md) print settings, and confirm counts against the [parts list](README.md).
2. Sort hardware into labeled trays: M4 T-nuts (150), M4/M3 bolts by length (10/12/16 mm — 20 each), M3 standoffs (30), M3 headless nuts (30), corner brackets (16), in-corner slot connectors (8).
3. Cut the 20×20 mm aluminium extrusions to length on the miter saw: six 350 mm, four 300 mm, four 200 mm. Deburr all cut ends.
4. Have your tool set ready: M2/M3/M4 screwdrivers and Allen keys, T2/T3/T4 Torx, soldering iron (for wiring safety net).

### 1. Build a frame using 20mm x 20mm extrusions
The frame has three extrusion positions front-to-back: **front** and **back** (the true corners) plus a **middle** position that sits between them. Looking at the rack from the left side: front is on the right, back is on the left, and the middle extrusions sit between the two — this is the mounting line for every module's back plate (MB-Mount-Back-Plate, HDD-Mount-Back-Plate, Power-Mount-Back-Plate).

1. Build two identical rectangles — one for the top, one for the bottom — each from two 300 mm extrusions (depth direction, front-to-back) and two 200 mm extrusions (width direction, left-to-right), joined at the four corners with **in-corner slot connectors**. These four corners are the front-left, front-right, back-left, and back-right positions.
2. Slide **M4 sliding T-nuts** into every extrusion channel that will receive a bolted part before you close up the frame — it's far easier to load them now than after the box is closed.
3. Stand the two rectangles apart and join front-left↔back-left and front-right↔back-right with four of the six 350 mm extrusions (the front and back verticals), using in-corner slot connectors. Reinforce all 8 corner joints with **corner brackets** (16 total, 2 per corner).
4. Fit the remaining two 350 mm extrusions as the **middle** verticals (left and right), positioned mid-span along the 300 mm depth rails — not at a corner. Secure each to the depth rails at top and bottom with a sliding T-nut and bracket. These are the back-plate mounting extrusions referenced in later steps.
5. The gap between the middle and back verticals is reserved for cable management (on the 4-Node build, this same slot also houses a vertically-mounted 1U switch — not applicable to the 2-Node's parts list).
6. Check the frame is square before fully tightening.

### 2. Attach the feet
1. Bolt the 4x **Foot.stl** parts to the underside corners of the bottom frame rectangle using M4 bolts into the T-nuts already in the channel.

> Note: Feet placement must align with the feet cutouts in the **Bottom-cover** — position them to match before final tightening, otherwise the bottom cover won't seat correctly in step 10.

### 3. Assemble the PSU mounting
Builds the standalone PSU-mount unit from **Power-Mount-Base**, **Power-Mount-Grill**, and **Power-Mount-PCB-Holder-Plate** (the PCB Holder is the tall slotted plate the harvested PSU PCBs will mount to in step 5; the Grill is the vented side panel; the Base is the flat tray both sit in).

1. Position the Grill and PCB-Holder-Plate together at the ridge where they meet, and seat both into the Power-Mount-Base.
2. Secure through the screw holes along the Base's lip with all nuts and bolts, and fully tighten.
3. Only once everything is bolted and tightened, pin stake / hot pin the Grill-to-PCB-Holder ridge (heat-staked plastic pins) as the final, permanent weld between the two parts.

### 4. ATX PSU dismantling
1. With both 400W ATX PSUs unplugged and discharged, open each case and remove the internal PCB from its metal shell. Keep each PSU's original screws/fan aside in case they're needed for the fan-mount in step 9.

### 5. Mount the harvested PCBs on the PCB Holder
1. Using the slotted holes on the PCB-Holder-Plate, mount each harvested PSU PCB with an M3 headless screw (12 mm), placing a 10 mm M3 spacer on both sides of the plate at each mounting point (spacer — PCB Holder — spacer). The slots allow the mounting position to be adjusted to match each PSU PCB's hole pattern.

### 6. Wire the power module and install it in the frame
1. Wire the AC power aggregation:
   - Terminate the IEC C14 10A inlet leads with the **push-fit lugs**.
   - Use the **LT-633** and **LT-933** quick-connect terminals to split/aggregate the inlet's Live and Neutral onto both PSUs' AC inputs in parallel, using the 3-core 1.5 mm² cable.
   - Route Earth to both PSU chassis grounds.
2. Fit the **Power-Mount-Back-Plate** to the frame's middle extrusion for this bay.
3. Secure the completed PSU-mount assembly (base + grill + PCB holder + PSUs) into the bottom bay of the frame, against the back plate.

### 7. Build each motherboard module (repeat ×2)
1. Fit M3 standoffs (female-to-female, 10 mm) into the **MB-Mounting-Plate** at the motherboard's standoff pattern, secured with M3 screws.
2. Mount the Mini-ITX motherboard onto the standoffs.
3. Attach the **MB-IO-Panel** over the board's I/O shield opening, at the front of the module — the motherboards are oriented I/O-out-front, not rear.
4. Mount the 2 push buttons for this node into the MB-IO-Panel using their push-button wire sets. Wiring these to the motherboard's front-panel power/reset headers is out of scope for this empty-enclosure build and is covered separately.
5. Fit the **MB-Mount-Back-Plate** behind the plate to close off and support the module.
6. Slide the completed module into its bay in the frame and bolt through the extrusion T-nuts.

### 8. Build each HDD module (repeat ×2)
1. Seat 2.5" drives into the **HDD-Mount**.
2. Close it out with the **HDD-Mount-Back-Plate**.
3. Mount the HDD module into the frame adjacent to its node's motherboard module, and wire SATA power/data to the corresponding motherboard.

### 9. Install fans
1. Fit the 4x **Fan-Cut-120** grills at the intake/exhaust cutouts — one pair (push-pull) for the node compartment, one pair for the power compartment.
2. The 2 PSU fans (built into the ATX PSUs) connect directly to each PSU's own fan pins — no separate wiring needed.
3. Mount the 2 additional 120mm fans behind the remaining grills, oriented for push-pull airflow with the PSU fans. These can be PWM or 12V fans, per user choice.
4. Power the 2 additional fans either from the motherboard's fan header (PWM or 12V, depending on fan type) or from a 12V PSU Molex connector — whichever the user prefers.

### 10. Cable dress and final checks
Do this before the back panels go on in step 11 — you need access to the wiring for this.

1. Route all internal wiring (PSU-to-motherboard, SATA, fan, push-button) along the frame rails, away from fan blades, and secure with the banding parts.
2. Double-check the AC wiring: continuity, no shorts to chassis, correct Live/Neutral/Earth landing on both PSUs.
3. Re-torque all M4/M3 fasteners and confirm the frame is still square.
4. Power on with no motherboards seated first (PSU + fans only) to confirm the aggregated AC wiring and fan wiring are correct before re-seating and powering the nodes.
5. Power on both nodes via the front push buttons and confirm boot.

### 11. Close up the panels and covers
1. Fit the **Left-Side-Panel-120mm-Fan-Power-Cut** on the side that carries the IEC inlet and power cutout.
2. Fit the 3x **Right-Side-Panel-120mm-Fan-Cut** panels on the remaining side positions (node bay ×2 sides + power bay).
3. Attach the 2x **Back-Cover** panels over the true rear of the enclosure — these are plain panels with no I/O or vent cutouts, since the motherboard I/O faces front.
4. Fit the **Bottom-cover** and **Top-Cover**.
5. Attach the 2x **Handel** (handle) parts to the top cover.
6. Fit the **25x265 Banding** strips (2x) as retention/cable-management banding across the relevant bay.
7. Close up and label the unit.

### Reference
- [Parts list / BOM](README.md)
- [STL — ABS print settings](../STL/ABS/README.md)
- [STL — PLA/PETG print settings](../STL/PLA_PETG/README.md)
- [2-Node render](../img/2-Node.png)
- [4-Node build photos](../img/4-Node) (2-Node = bottom half of this build)

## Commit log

2025-11-04 STL Files
    STL Files
    [3d-2025-001.stl, 3d-2025-002.stl, 3d-2025-003.stl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]
2025-11-06 Updates to STL and Docs
    [3d-2025-001.stl, 3d-2025-002.stl, 3d-2025-003.stl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]
2025-11-20 Adds STL Files
    [3d-2025-11-ABS-PLUS-001a.stl, 3d-2025-11-ABS-PLUS-001b.stl, 3d-2025-11-ABS-PLUS-002a.stl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]
2025-11-21 Update to Sample parts
2025-11-22 Updates the repository Direcotry sstructure and Documentation
    [2_NODE_BOM.csv]
2025-12-03 Adds 4 Node Bom
    [2_NODE_BOM.csv, 4_NODE_BOM.csv]
2025-12-03 Adds 2-Node 360 View
    [2-Node-Unit-360-View.stl]
2025-12-13 The part was too sensitive to vibrations; this was causing print defects and breakage during assembly. Added additional support
    [3d-2025-11-ABS-PLUS-001a.stl]
2025-12-19 Minor change to reduce printing time support
    [3d-2025-11-ABS-PLUS-001b.stl]
2026-04-08 HDD case modified
    HDD case modified
    [3d-2025-11-ABS-PLUS-001a.stl]
2026-04-22 Major Design Change
    Due to 3D FDM Printing limits I had to make changes to the components. This made all the build instruction invalid.
    [2-Node-Unit-360-View.stl, 2_NODE_BOM.csv, 2_NODE_BOM_electronics.csv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]
2026-04-24 Design change
    The parts were causing Printer hardware to fail. Had to change the design. None of the old data is valid now
    [IO-Plate-V1.stl, MB-IO-Panel.stl, MB-Mounting-Plate.stl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]
2026-05-14 STL - Printed parts
    STL - Printed parts
    [Bottom-cover.stl, Cover-Template.dxf, Foot.stl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]
2026-05-14 Removes old design files
    Removes old design files
    [3d-2025-11-PLA-001.stl, 3d-2025-11-PLA-002.stl, 3d-2025-11-PLA-003.stl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]
2026-05-14 New Side Panels
    [Fan-Cut-120.stl, Left-Side-Panel-120mm-Fan-Power-Cut.stl, Left-Side-Panel-120mm-Fan-Switch-Cut.stl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]
2026-06-15 Final Parts
    [240mm-Banding.stl, 25x265 Banding.f3d, 25x265 Banding.stl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]
2026-06-15 Updates BOM
    [25x265 Banding.f3d]
2026-06-15 Update to a few files
    [Cover-Template.dxf]
